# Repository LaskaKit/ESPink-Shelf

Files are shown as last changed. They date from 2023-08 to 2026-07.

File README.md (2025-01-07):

# LaskaKit ESPink-Shelf-213 and ESPink-Shelf-29 ESP32 e-Paper 

A small development board that has been designed primarily for lowest power consumption and convenient programming.</br>
This is the ESPink Shelf 213 and ESPink Shelf 29, a board equipped with [ePaper with 2.13"](https://www.laskakit.cz/good-display-gdey0213b74-2-13--250x122-epaper-displej/) and [ePaper with 2.9"](https://www.laskakit.cz/laskakit-espink-shelf-2-9-esp32-e-paper/?variantId=14193) dimension.</br>

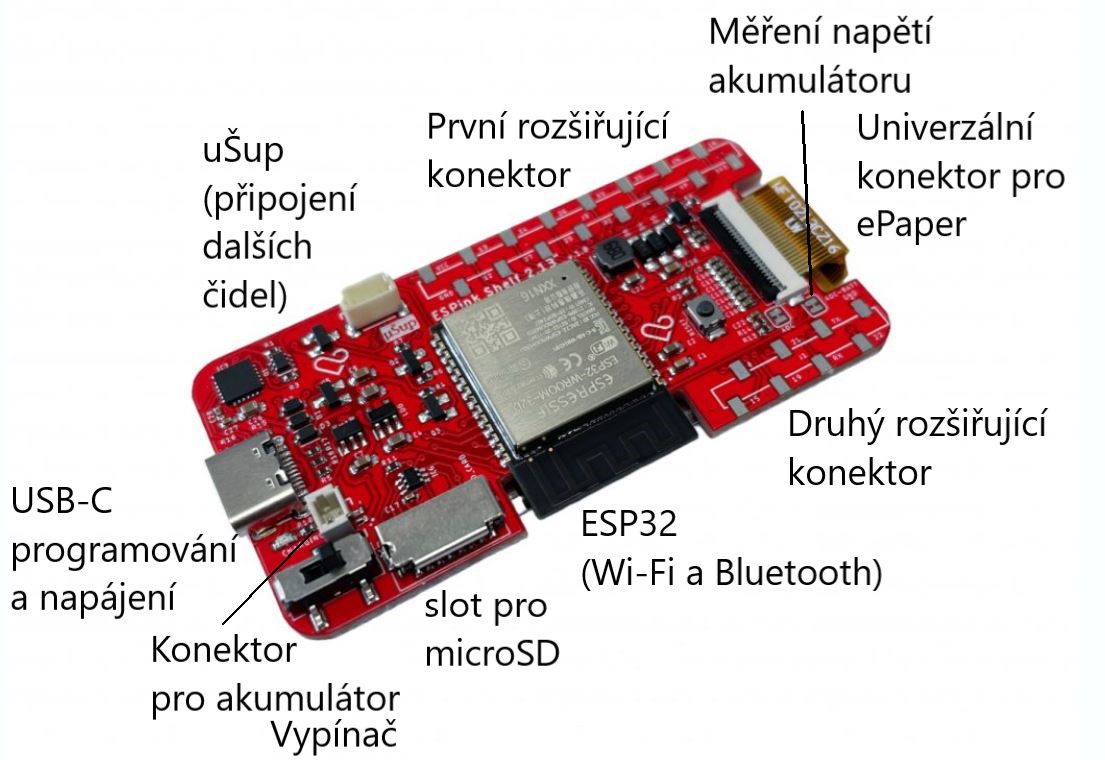
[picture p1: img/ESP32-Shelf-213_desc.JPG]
Description


And how did we achieve such a low power consumption - 12.5 uA? The ESP32 is a powerful chip that allows you to connect to Wi-Fi and Bluetooth, but it is also very power efficient, about 5 uA, even in deep-sleep mode.
The ePaper consumes power especially during the update of the display, but every uA counts so we added a MOSFET to the power supply to disconnect from source the ePaper when it is not updated.

But we don't stop there - there is also i [uŠup connector](https://blog.laskakit.cz/predstavujeme-univerzalni-konektor-pro-propojeni-modulu-a-cidel-%CE%BCsup/), this is a 4 pin connector to which we have a wide range of accessories and has a standard size and pinout. 3.3V power supply, GND and I2C bus. Accessories include [cables with variable length](https://www.laskakit.cz/--sup--stemma-qt--qwiic-jst-sh-4-pin-kabel-10cm/), [the cables with female duponts](https://www.laskakit.cz/--sup--stemma-qt--qwiic-jst-sh-4-pin-kabel-dupont-samice/) or [the cables with hooks](https://www.laskakit.cz/--sup--stemma-qt--qwiic-jst-sh-4-pin-kabel-s-testovacim-hackem/) for fast debug.  </br>

The I2C connector power supply can also be disconnected just like the ePaper - the MOSFET switches are GPIO2 control.
So the GPIO2 controlls the switching of power supply for ePaper and also for I2C sensors connected to uŠup connector. 

And what another modules you can use? For example the sensor [SCD41 for measurement of CO2, temperature and humidity](https://www.laskakit.cz/laskakit-scd41-senzor-co2--teploty-a-vlhkosti-vzduchu/), sensor SHT41 [temperature nad humidity](https://www.laskakit.cz/laskakit-sht40-senzor-teploty-a-vlhkosti-vzduchu/) and [sensor of pressure, temperature, humidity BME280](https://www.laskakit.cz/arduino-senzor-tlaku--teploty-a-vlhkosti-bme280/), [RTC - Real Time Clock](https://www.laskakit.cz/laskakit-ds3231-orig--rtc-hodiny-realneho-casu/) with DS3231 or [OLED display with 1.3" dimension and 128x64px resolution](https://www.laskakit.cz/laskakit-oled-displej-128x64-1-3--i2c/?variantId=11903).

The board can be disconnected from source thanks to switch. The USB-C connector located on the board is used for both programming and charging the battery, which you can of course plug in. 
For convenient programming, the fitted USB-UART converter CH9102F is used, which excels both in speed and low self-consumption.
If you need more memory, there is also a microSD card slot where you can store icons or images. 

There is also a voltage divider on the board that is connected to the battery and the ESP32 can measure the voltage. It can then perform an action based on the voltage - for example, to warn of a low battery voltage. The divider is connected to the GPIO34 pin.

We have prepared some sample codes for you to use with this board. The most interesting is the code called "[Date_BusConnection_WeatherForecast](https://github.com/LaskaKit/ESPink-Shelf/tree/main/SW/Date_BusConnection_WeatherForecast)", where, in addition to displaying the current date, the weather forecast and the next public transport departures - such as buses or trams - are also displayed. 

You can find the development board on our e-shop https://www.laskakit.cz/laskakit-espink-shelf-213-esp32-e-paper/
and https://www.laskakit.cz/laskakit-espink-shelf-2-9-esp32-e-paper/?variantId=14193

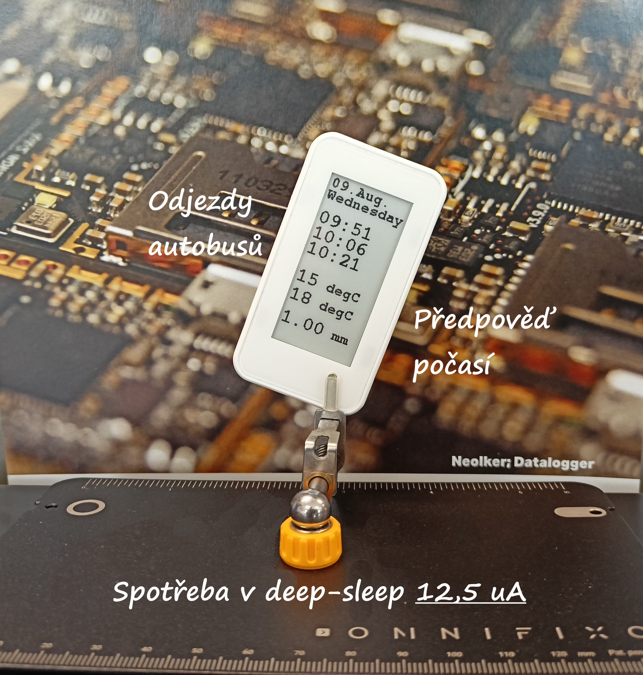
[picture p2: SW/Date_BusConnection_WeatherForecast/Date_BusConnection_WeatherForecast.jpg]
Bus


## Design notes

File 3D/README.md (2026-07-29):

#### Enclosure file moved to : https://github.com/LaskaKit/Live/tree/main/Shelf_2-13_inch and https://github.com/LaskaKit/Live/tree/main/Shelf_2-9_inch

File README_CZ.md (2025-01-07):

# LaskaKit ESPink-Shelf-213 ESP32 e-Paper a ESPink-Shelf-29

Malá, designově povedá vývojová deska, která byla navržena především na co nejnižší spotřebu proudu a pohodlné programování.</br>
To je ESPink Shelf 213 a ESPink Shelf 29, deska osazené [ePaper o velikosti 2.13"](https://www.laskakit.cz/good-display-gdey0213b74-2-13--250x122-epaper-displej/) a [ePaper o velikosti 2.9"](https://www.laskakit.cz/laskakit-espink-shelf-2-9-esp32-e-paper/?variantId=14193).</br>
[LaskaKit ESPink-4.2 ESP32 e-Paper](https://www.laskakit.cz/laskakit-espink-42-esp32-e-paper-pcb-antenna/?variantId=13538) a [LaskaKit ESPink-Shelf-4.26 ESP32 e-Paper](https://www.laskakit.cz/laskakit-espink-4-26-esp32-s3-e-paper/).</br>
Pokud preferuješ samostatnou desku, pak máme v nabídce [velmi úsporný a univerzální ESPink](https://www.laskakit.cz/laskakit-espink-esp32-e-paper-pcb-antenna/?variantId=12419). Deska je menší a univerzálnější pro připojení jiných ePaper displejů. </br>

Popis desky

A jak jsme dosáhli tak nízké, , 12,5 uA, spotřeby? ESP32 je výkonný čip umožňující se připojit na Wi-Fi a Bluetooth, ale kromě toho je velmi úsporný, cca 5 uA, i v režimu hlubokého spánku (tzv. deep-sleep mode).</br>
ePaper spotřebovává energii zejména při přepisu data na displeji, každá uA se ale počítá a tak jsme přidali na napájení MOSFET, kterým odpínáme napětí v případě, že ePaper není aktualizován. </br>
Tím ale ještě nekončíme - na desce je i[ uŠup konektor](https://blog.laskakit.cz/predstavujeme-univerzalni-konektor-pro-propojeni-modulu-a-cidel-%CE%BCsup/), to je 4 pinový konektor ke kterému máme bohaté příslušenství a má standardní rozměr a pinout. 3,3V napájení, GND a a I2C sběrnici. Mezi příslušenství patří [kabely různých délek zakončené steným konektorem](https://www.laskakit.cz/--sup--stemma-qt--qwiic-jst-sh-4-pin-kabel-10cm/), [kabely zakončený dupont dutinkami](https://www.laskakit.cz/--sup--stemma-qt--qwiic-jst-sh-4-pin-kabel-dupont-samice/) nebo [kabely zakončené háčky](https://www.laskakit.cz/--sup--stemma-qt--qwiic-jst-sh-4-pin-kabel-s-testovacim-hackem/) pro rychlé a spolehlivé testování.  </br>

Napájení I2C konektoru lze také odpojit napájení stejně jako ePaperu - MOSFET spínače jsou řízení GPIO2. </br>
GPIO2 tedy řídí/spíná jak napětí pro ePaper, tak i pro I2C čidla připojená na uŠup konektor. </br>

A jaké moduly to mohou být? Třeba čidlo [SCD41 pro měření CO2, teploty a vlhkosti vzduchu](https://www.laskakit.cz/laskakit-scd41-senzor-co2--teploty-a-vlhkosti-vzduchu/), čidla SHT41 [teploty a vlhkosti vzduchu](https://www.laskakit.cz/laskakit-sht40-senzor-teploty-a-vlhkosti-vzduchu/) a [čidla tlaku, teploty a vlhkosti vzduchu BME280](https://www.laskakit.cz/arduino-senzor-tlaku--teploty-a-vlhkosti-bme280/), [RTC Hodiny reálného času](https://www.laskakit.cz/laskakit-ds3231-orig--rtc-hodiny-realneho-casu/) s DS3231 nebo [OLED displej o velikosti 1.3" a rozlišení 128x64px](https://www.laskakit.cz/laskakit-oled-displej-128x64-1-3--i2c/?variantId=11903).

Deska lze samozřejmě kompletně vypnout díky integrovanému přepínači. USB-C konektor umístěný na desce slouží jak pro programování, tak i nabíjení akumulátoru, který můžete samozřejmě připojit. </br>
Pro pohodlné programování slouží osazený USB-UART převodník CH9102F, který vyniká jak rychlostí, tak i nízkou vlastní spotřebou.</br>
V případě potřeby větší paměti pak máme osazený ještě slot pro microSD kartu, kam můžeš uložit ikony nebo obrázky. </br>

Na desce je osazen i dělič napětí, který je připojen na akumulátor a ESP32 může měřit napětí. Na základě napětí pak provést nějakou akci - například upozornit na nízký stav napětí baterie. Dělič je připojen na pin GPIO34.</br>

Deska podporuje populární projekt Živý Obraz, který výrazně zjednodušuje použití ePaper displeje k zobrazení fotografií, (google, outlook, apple) kalendáře, kurzů, hodnot z meteostanic, předpovědi počasí a mnoho dalšího. Není nutné psát kód, stačí nahrát správný typ ePaper a desky skrze webové prostředí a dodržet postup popsaný v [dokumentaci](https://wiki.zivyobraz.eu/).</br>
Program nahraješ [přes webové prostředí na této stránce](https://zivyobraz.eu/?page=instalace) a stačí zvolit desku <b>LaskaKit ESPink 2.x</b> a typ ePaperu <b>GDEY029F51H, GDEY029T71H, GDEY029T94 nebo GDEY0213B74</b> - podle toho, co sis objednal. </br>

K této desce jsme připravili několik vzorových kódů, které můžeš využít. Nejzajímavější je kód nazvaný "[Date_BusConnection_WeatherForecast](https://github.com/LaskaKit/ESPink-Shelf/tree/main/SW/Date_BusConnection_WeatherForecast)", kde kromě zobrazení aktuálního data je zobrazena i předpověd počasí a následující odjezdy MHD - třeba autobusů nebo tramvají. 

Vývojovou desku najdeš na našem e-shopu https://www.laskakit.cz/laskakit-espink-shelf-213-esp32-e-paper/
 a https://www.laskakit.cz/laskakit-espink-shelf-2-9-esp32-e-paper/?variantId=14193

Autobusy

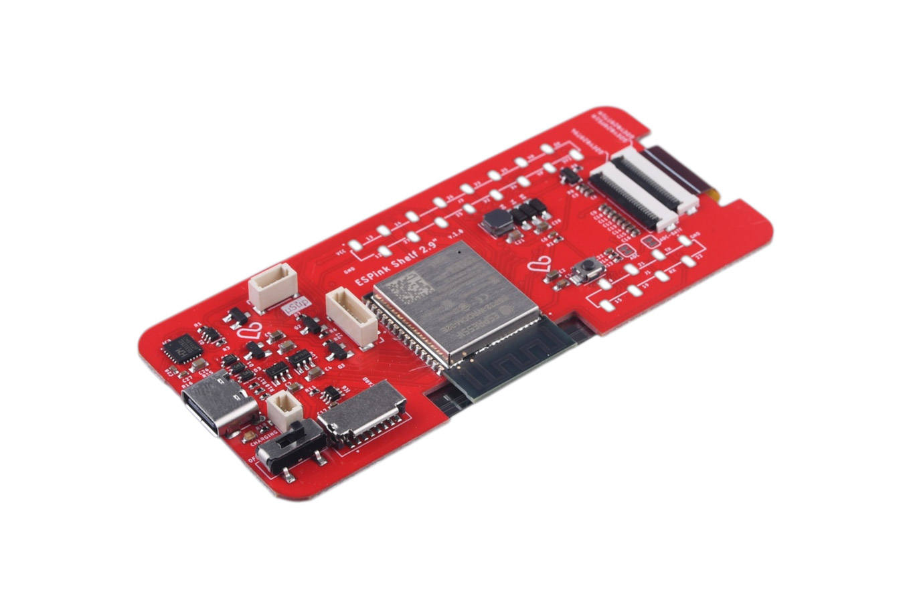
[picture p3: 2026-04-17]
img/laskakit-espink-shelf-2-9-esp32-e-paper-2.jpg

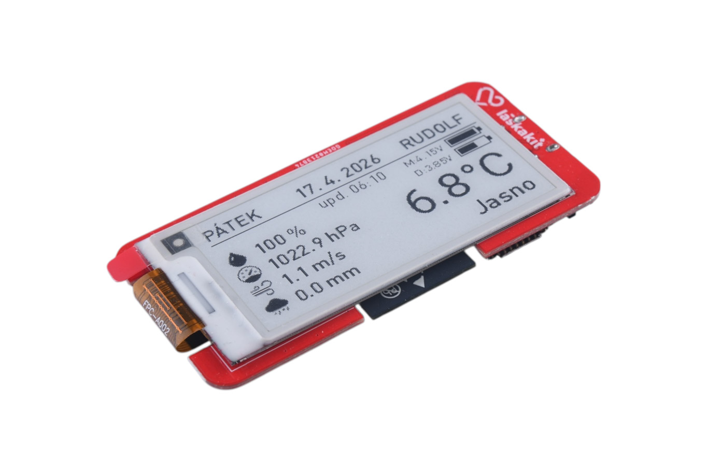
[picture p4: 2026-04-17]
img/laskakit-espink-shelf-213-esp32-e-paper-1.jpg

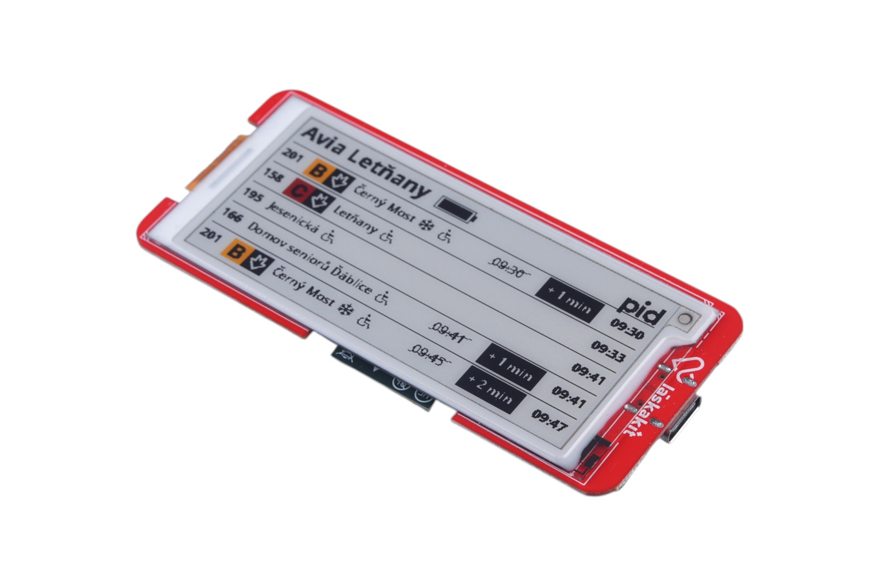
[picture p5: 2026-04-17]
img/laskakit-espink-shelf-2-9-esp32-e-paper-3.jpg

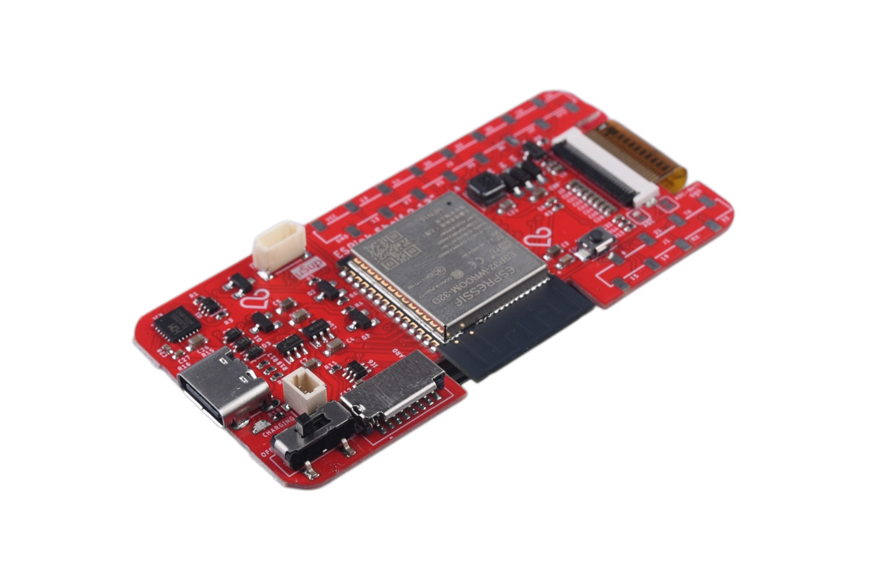
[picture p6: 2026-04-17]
img/laskakit-espink-shelf-213-esp32-e-paper-2.jpg

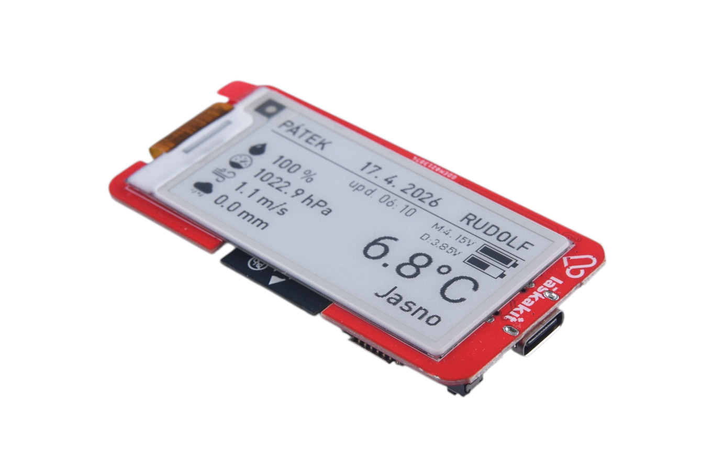
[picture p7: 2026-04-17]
img/laskakit-espink-shelf-213-esp32-e-paper-3.jpg

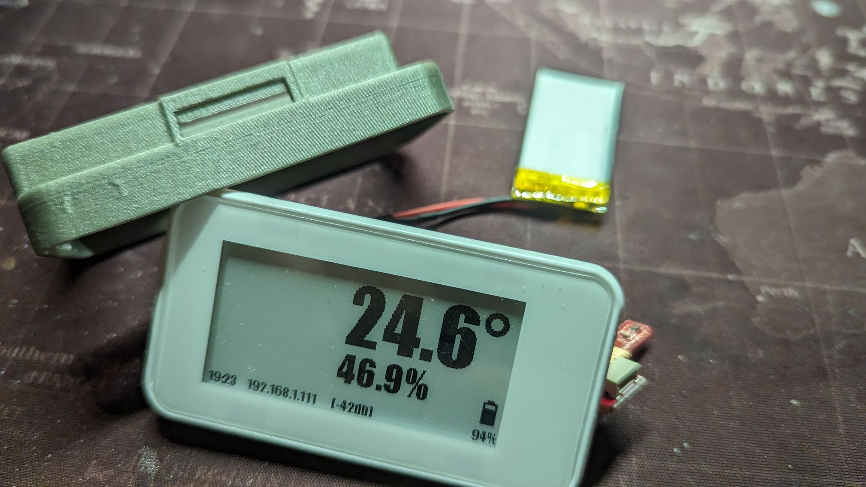
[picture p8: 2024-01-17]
SW/esphome/byHavlas/face.jpg

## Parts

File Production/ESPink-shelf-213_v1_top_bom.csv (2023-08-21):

Comment | Designator | Footprint | LCSC Part #
0.47R | R9 | R0402
1.3M | R14 | R0402
1M | R13 | R0402
1k | R5 R7 | R0402
1uF | C3 | C0402K
1uF | C7 | C0603
1uF | C8 C9 C10 C11 C12 C13 C14 C15 C16 | C0402K
4 7uF | C5 | C0603 | C108344
4.7uF | C20 | C0603
5.1k | R15 R16 | R0402
10k | R1 R2 R3 R8 R11 R17 | R0402
10uF | C21 | C0603
22uF | C4 C23 C26 | C0603
47uF | C2 | C0603 | C178330
68uH | L1 | SMNR4020 | C135265
100k | R4 R6 R18 | R0402
100n | C27 C28 | C0402
100nF | C1 | C0603
100nF | C6 | C0402K
100nF | C17 C22 | C0402
330 | R10 | R0402
AFC34-S24FIA-00 | J5 | AFC34S24FIA00
AO3400A | Q4 | SOT23-3 | C20917
AO3401 | Q3 Q5 | SOT23
BAT60B | D1 D2 D3 | SOD323-R | C514095
CH9102F | IC3 | QFN24-4X4
EN button | RESET | TS1088R02026 | C455280
ESP32-WROOM | ESP32 | ESP32WROOM32D | C529578
HT7833 | LDO | SOT23-5
JST-SH-2P | J6 | 1X02_1MM_RA_VERT | C479987
JST-SH-4P | J2 | 1X04_1MM_RA_VERT | C371588
JUMPER-SMT_2_NC_TRACE_SILK | ADC ADC-BATT | SMT-JUMPER_2_NC_TRACE_SILK
MBR0530 | D4 D5 D6 | SOD123-F
MMDT3904 | Q1 | SC70-6 | C268586
MOSFET_P-SOT-23 | Q9 | SOT23
RED | CHARGING | CHIP-LED0603 | C2286
S8050 | Q2 | SOT23-BEC
SLIDE_SWITCH_TA-3530A-A2 | S1 | TA-3530A-A2 | C514025
SMF05C | IC6 | SOT65P210X110-6N | C558425
TF-123-ARP9H17 | SD_CARD | HANBO_TF-027-H300 | C5310495
TP4054 | U1 | SOT-23-5 | C32574
USB-C_2-16PIN | J4 | USBC_USB-C-16P-5 | C2837092
X6511WVS-08H-C60D48R2 | J1 | X6511WVS08HC60D48R2
X6511WVS-16H-C60D48R1 | J3 | X6511WVS16HC60D48R2

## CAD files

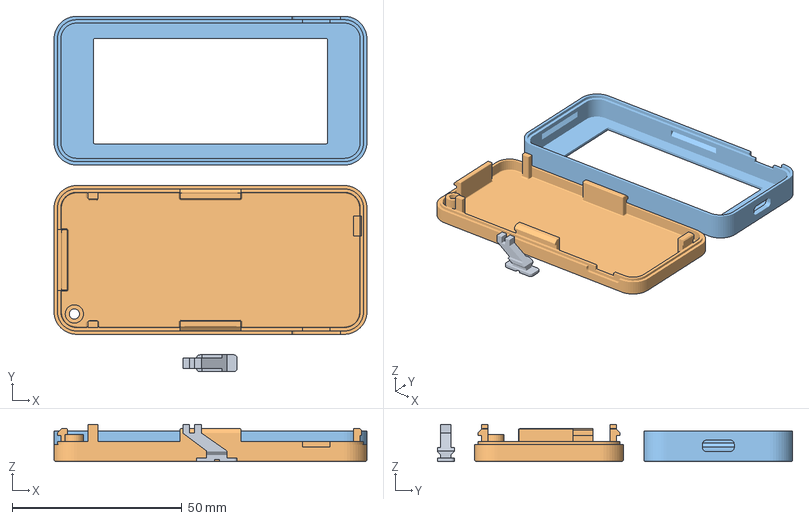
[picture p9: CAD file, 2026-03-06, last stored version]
3D/Case/ESPink-Shelf-29_case.3mf
92.1 x 104.6 x 10.9 mm
ESPink-Shelf-29_case
back v24
face v21

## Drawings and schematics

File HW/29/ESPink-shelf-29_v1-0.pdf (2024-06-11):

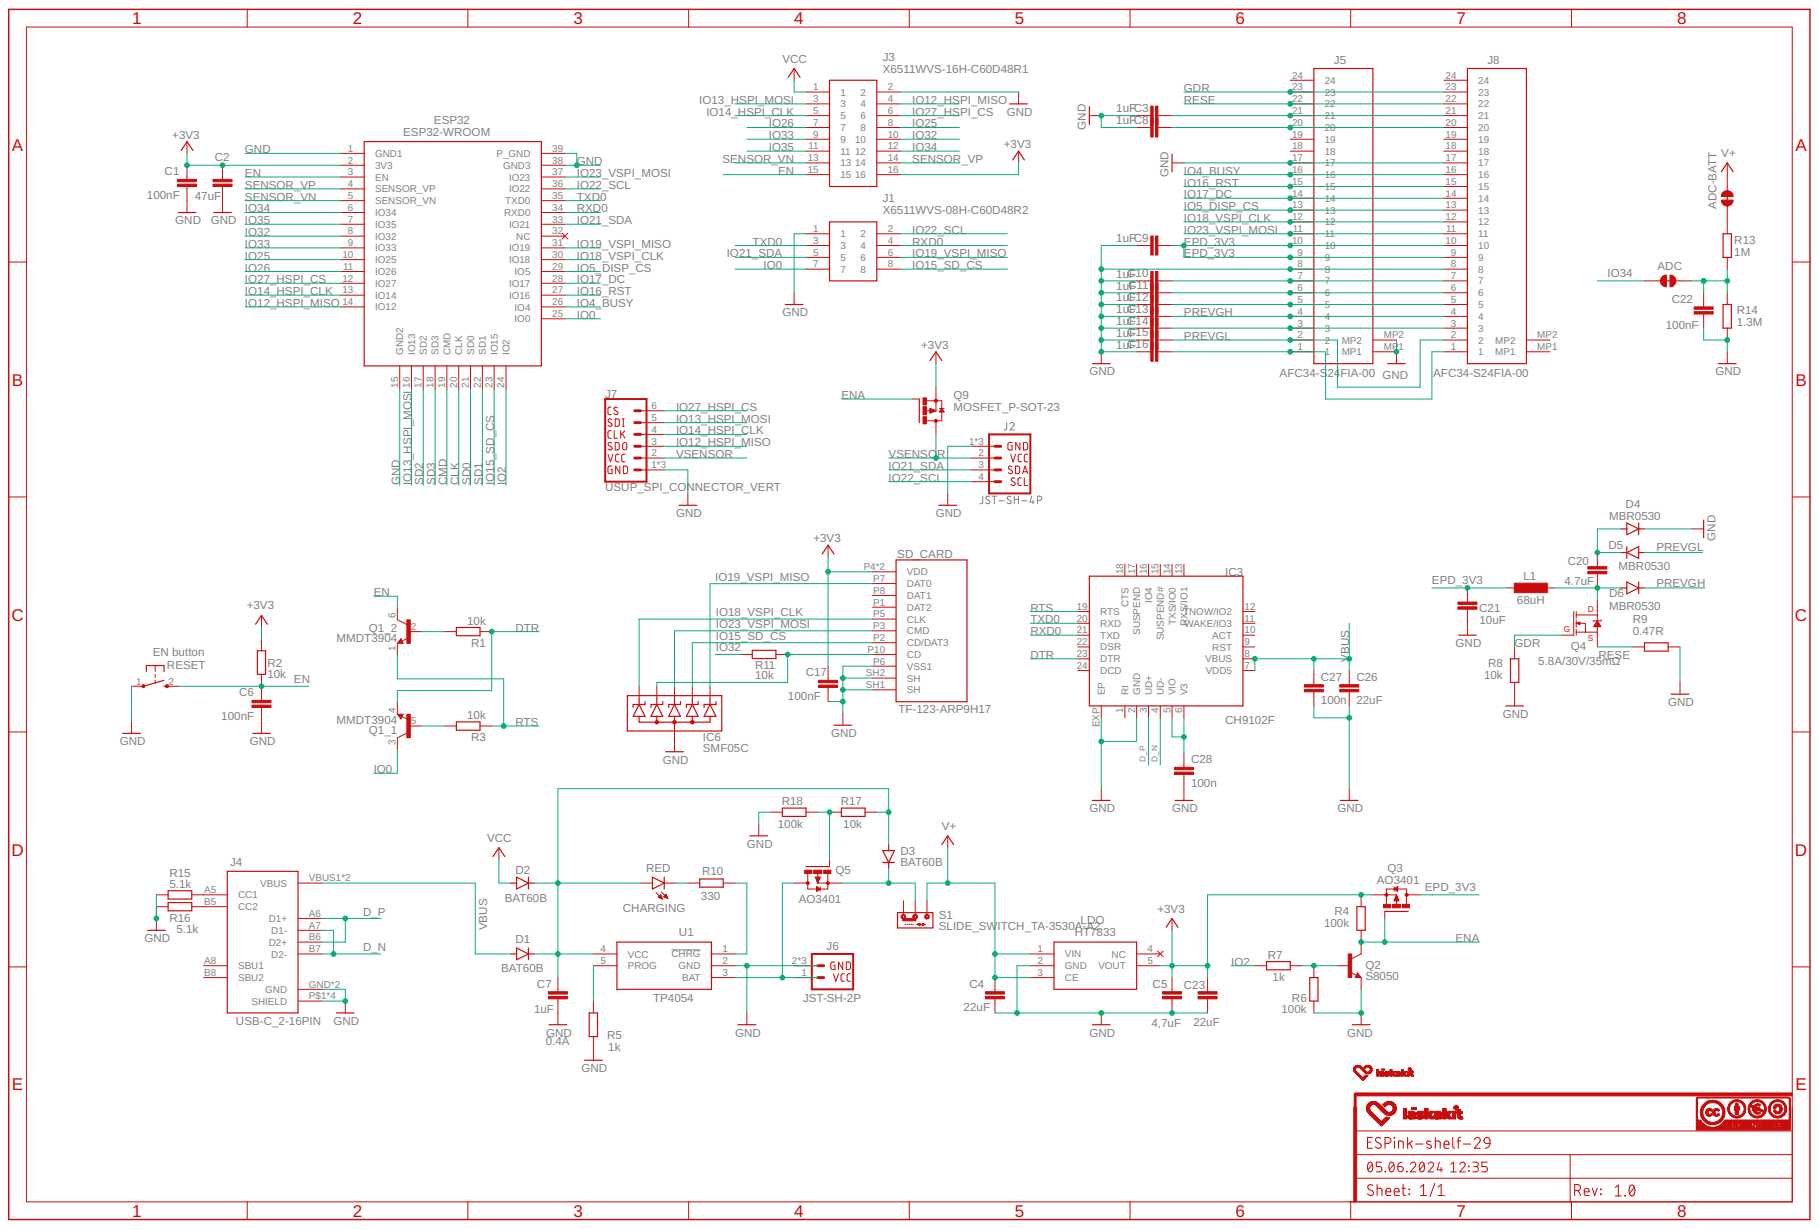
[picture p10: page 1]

1uF | 3 | 3 | 3
1uF | PREVGL 2 | | 2

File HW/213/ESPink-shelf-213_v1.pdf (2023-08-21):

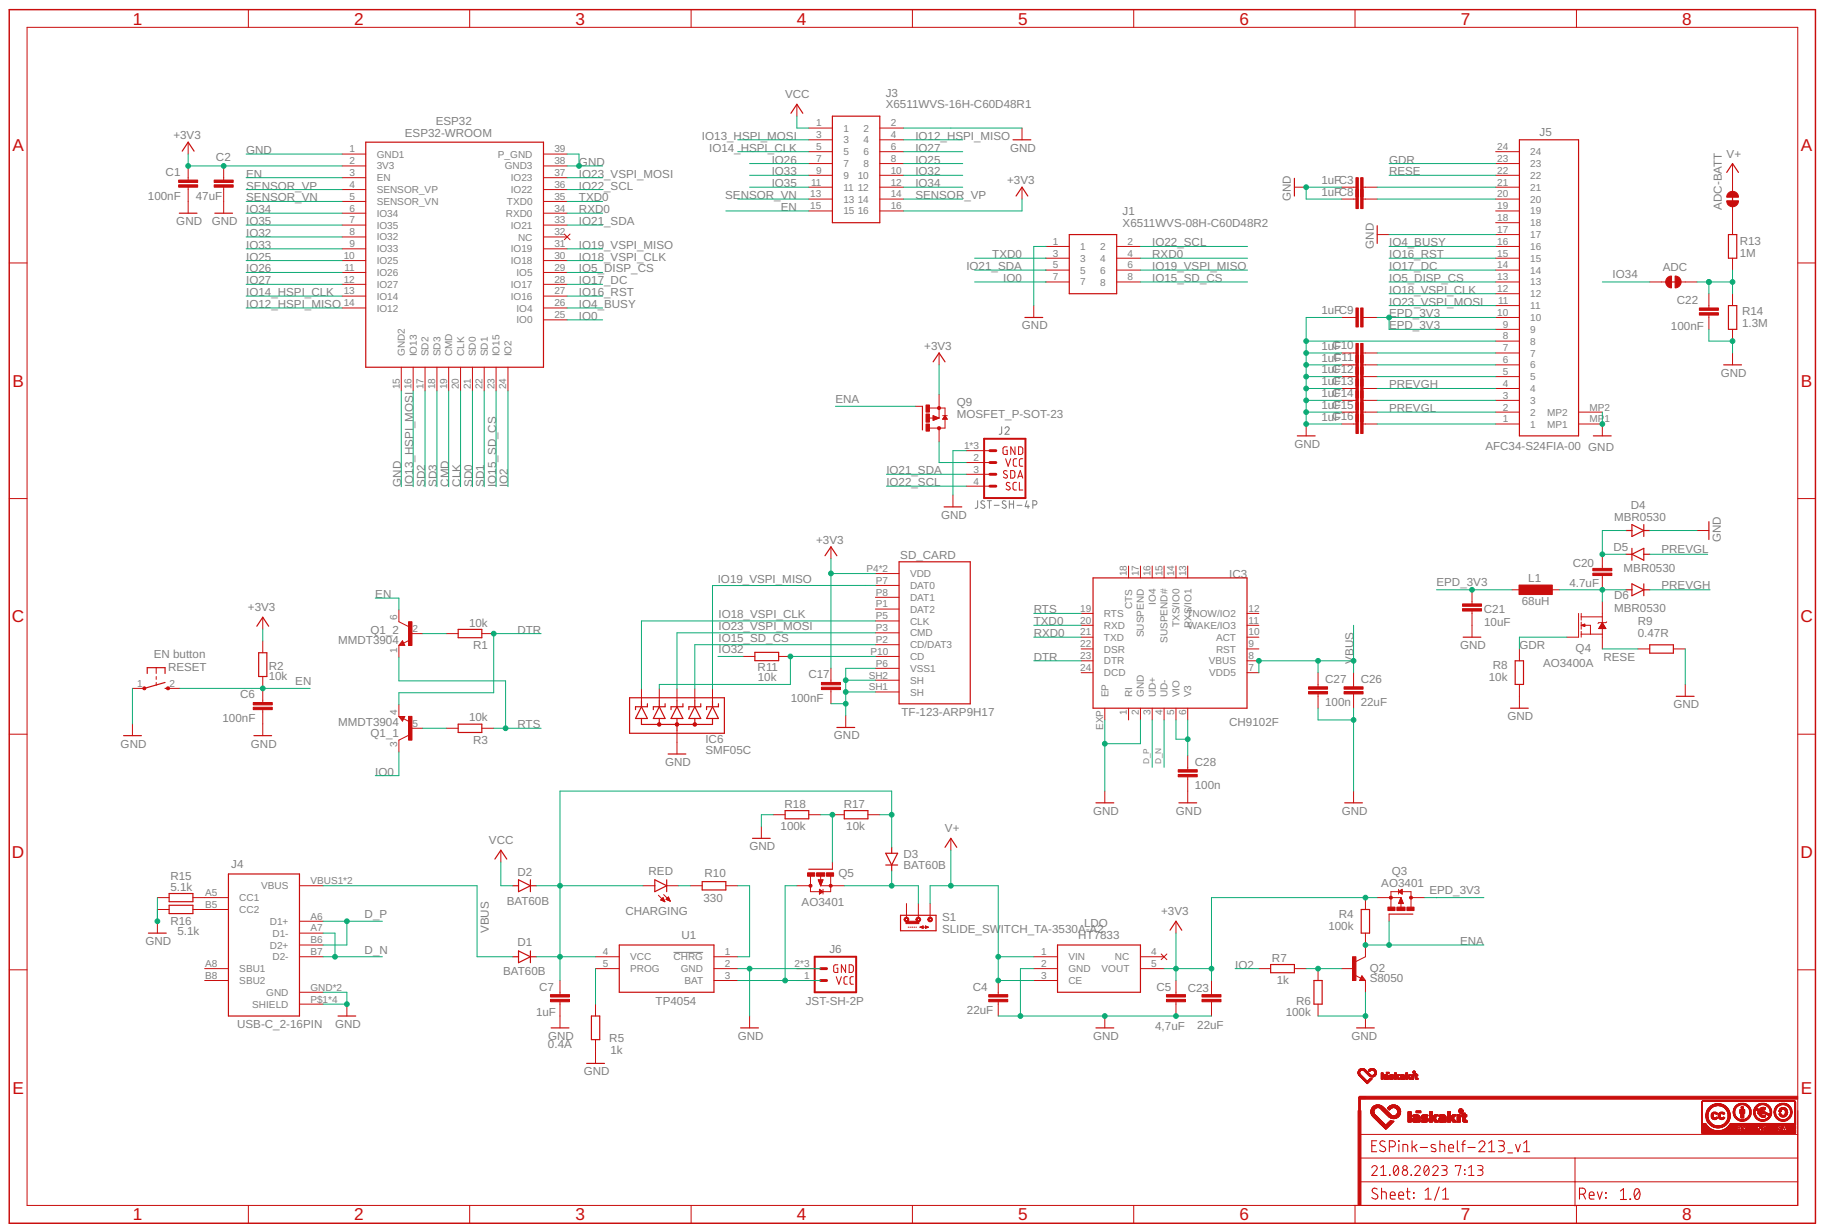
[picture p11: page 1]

1uF | 6
1uF | 5
1uF | PREVGH 4
1uF | 3
1uF | PREVGL 2
1uF | 1

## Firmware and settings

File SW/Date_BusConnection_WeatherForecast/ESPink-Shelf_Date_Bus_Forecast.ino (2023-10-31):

/* Example code for LaskaKit ESPInk-Shelf
 * where are shown the date, bus departure and weather forecast
 * 
 * Board:   LaskaKit ESPink-Shelf https://www.laskakit.cz/laskakit-espink-shelf-213-esp32-e-paper/
 * Display: Good Display GDEW0213T5D         
 * 
 * Email:podpora@laskakit.cz
 * Web:laskakit.cz
 *
 *  Libraries:
 *  ArduinoJSON https://arduinojson.org/
 *  NTP https://github.com/arduino-libraries/NTPClient
 *  GxEPD2 https://github.com/ZinggJM/GxEPD2
 *
 *  Used Forecast data from https://github.com/petrbrouzda/YrNoProvider
 *
 *	What customer shall change:
 *  Bus.h -> fill your departure time, working days, saturday and sunday are split
 *  config.h -> fill your location, Wi-Fi credentials
 */



#define ENABLE_GxEPD2_GFX 0

#include <WiFi.h>
#include <HTTPClient.h>

/*------- CONFIGURATION ----------*/
#include "config.h"

/*------- Arduino JSON ----------*/
#include <ArduinoJson.h>

/*------- BUS connection ----------*/
#include "Bus.h"

/*------- NTP ----------*/
#include "time.h"

/*------- ePaper ----------*/
#include <GxEPD2_BW.h>
#include <GxEPD2_3C.h>
#include <GxEPD2_7C.h>
#include <Fonts/FreeMonoBold9pt7b.h>
#include <Fonts/FreeMonoBold12pt7b.h>
#include <Fonts/FreeMonoBold18pt7b.h>
#include <Fonts/FreeMonoBold24pt7b.h>

//GxEPD2_BW<GxEPD2_213_T5D, GxEPD2_213_T5D::HEIGHT> display(GxEPD2_213_T5D(/*CS=5*/ SS, /*DC=*/ 17, /*RST=*/ 16, /*BUSY=*/ 4));         // ESPink-Shelf-213 GDEW0213T5D -> 2.13" 104x212, UC8151D
GxEPD2_BW<GxEPD2_213_B74, GxEPD2_213_B74::HEIGHT> display(GxEPD2_213_B74(/*CS=5*/ SS, /*DC=*/ 17, /*RST=*/ 16, /*BUSY=*/ 4));     // ESPink-Shelf-213 GDEM0213B74 -> 2.13" 122x250, SSD1680 

/*------- NTP ----------*/
struct tm timeinfo;

/*------- Arduino JSON config ----------*/
StaticJsonDocument<10000> doc;

void setup()
{
  Serial.begin(115200);
  delay(100);

  WiFi.begin(ssid, pass);
  Serial.println("Connecting");
  int count = 0;
  while(WiFi.status() != WL_CONNECTED) {
    delay(500);
    Serial.print(".");
    count++;
    if(count >= 20) // wait max 20s, if it is not connected, go to sleep
    {
      Serial.flush();
      esp_sleep_enable_timer_wakeup(sleepDuration * 1000000); // sleep for 10 minutes
      esp_deep_sleep_start(); 
    }
  }
  Serial.println();

  // WiFi connected
  if(WiFi.status()== WL_CONNECTED)
  {
    // turn on power to display
    pinMode(2, OUTPUT);
    digitalWrite(2, HIGH);   // turn on the ePaper
    delay(1000);   
    
    display.init(); // ePaper init
    display.setRotation(0);
    display.setTextColor(GxEPD_BLACK); // Set text color
    display.fillScreen(GxEPD_WHITE); // set the background to white (fill the buffer with value for white)

	/*------- Forecast ----------*/
    updateForecastData(jsonurl);
	
    /*------- NTP ----------*/
    configTime(gmtOffset_sec, daylightOffset_sec, ntpServer);
    
    if(!getLocalTime(&timeinfo))
    {
      Serial.flush();
      esp_sleep_enable_timer_wakeup(sleepDuration * 1000000); 
      esp_deep_sleep_start();
      Serial.println("Failed to obtain time");
      return;
    }
    Serial.println(&timeinfo, "%A, %B %d %Y %H:%M:%S");
    Serial.println(timeinfo.tm_wday);

    display.setFont(&FreeMonoBold9pt7b);
    display.setCursor(5, 15);
    display.print(&timeinfo, "%d.%b.");
    display.setCursor(5, 30);
    display.print(&timeinfo, "%A");
	
	  /*------- BUS connection ----------*/
	  updateBUSconnectionData();

    /*------- Update ePaper ----------*/
    display.display(false);

    display.powerOff();

    digitalWrite(2, LOW);   // turn off the ePaper
  }
  
  Serial.flush();
  esp_sleep_enable_timer_wakeup(sleepDuration * 1000000); 
  esp_deep_sleep_start(); 

}


void loop()
{
}

void updateBUSconnectionData()
{
	    /*------- Bus connection ----------*/
    int firstDepartureHour = 4; // first hour of departure
    int lastDepartureHour = 22; // last hour of departure
    int maxDepartureCount = 3; // max visible departures

    /*   DO NOT CHANGE IT  */
    int currMin = timeinfo.tm_min; // current minute from NTP server
    int currHour = timeinfo.tm_hour; // current hour from NTP server
    int departureCount = 0; // temp variable
    int posY = 60; // px possition of the first bus on ePaper (Y axis)
    int posX = 5; // px possition of the first bus on ePaper (X axis)
    int posYmove = 20; // move the next departure by this px number on ePaper
    display.setCursor(posX, posY);
    display.setFont(&FreeMonoBold12pt7b);

    // if current hour is in the range of firstDepartureHour and lastDepartureHour
    if((currHour >= firstDepartureHour) && (currHour <= lastDepartureHour))
    {
      Serial.println("Following BUS connection");
      for(int i = 1; i <= 9; i++) // search BUS between 1 to 9 time slot , means firstConnectionInMinutes, secondConnectionInMinutes, ...
      {
          int minuteConnection = 0;
          
          minuteConnection = busDepartureWD[currHour-firstDepartureHour][i]; // Working day array
          if((timeinfo.tm_wday == 0) || (timeinfo.tm_wday == 6)) // if Sunday, choose different array
          {
            if(timeinfo.tm_wday == 0)
            {
              minuteConnection = busDepartureSun[currHour-firstDepartureHour][i];
              Serial.println("Sunday");
            }
            if(timeinfo.tm_wday == 6)
            {
              minuteConnection = busDepartureSat[currHour-firstDepartureHour][i];
              Serial.println("Saturday");
            }
          }
            
          if((minuteConnection) == -1) // if no connection, exit the loop 
          {
              Serial.print("No BUS connection in "); Serial.println(currHour);
              break;
          }
          else // else show folling connection
          {
              if(currMin <= (minuteConnection))
              {
                  display.setTextColor(GxEPD_BLACK);

                  char departure[10] = {0};
                  sprintf(departure, "%02d:%02d", currHour, minuteConnection);
                  display.setCursor(posX, posY);
                  display.println(departure);
                  Serial.print("Next BUS connection in "); Serial.print(currHour); Serial.print(":"); Serial.println(minuteConnection);
                  departureCount++;
                  posY = posY + posYmove;
                  if(departureCount >= maxDepartureCount) // show mayDepartureCount connection
                  {
                      break;
                  }
              }
          }
      }
    }
    // if no connection, show first morning connection
    else
    {
        display.setCursor(posX, posY);
        int minuteConnection = 0;
        minuteConnection = busDepartureWD[firstDepartureHour-firstDepartureHour][1];
        if((timeinfo.tm_wday == 0) || (timeinfo.tm_wday == 6)) // if Sunday, choose the array for Sunday
        {
          if(timeinfo.tm_wday == 0)
          {
            minuteConnection = busDepartureSun[firstDepartureHour-firstDepartureHour][1];
            Serial.println("Sunday");
          }
          if(timeinfo.tm_wday == 6)
          {
            minuteConnection = busDepartureSat[currHour-firstDepartureHour][1];
            Serial.println("Saturday");
          }
        }

        char departure[10] = {0};
        sprintf(departure, "%02d:%02d", firstDepartureHour, minuteConnection);
        display.println(departure);
        Serial.print("Next BUS connection in "); Serial.print(firstDepartureHour); Serial.print(":"); Serial.println(minuteConnection);
    }

    // if less connection than maxDepartureCount, search the connection in the next hour
    if((departureCount < maxDepartureCount) && ((currHour >= firstDepartureHour) && (currHour <= lastDepartureHour)))
    {
        currHour = currHour + 1; // current hour + 1
        currMin = 0;
        
        if((currHour >= firstDepartureHour) && (currHour <= lastDepartureHour)) // check the hour is in the range
        {
          for(int i = 1; i <= 9; i++) // search minutes of connetions (first, second, ...)
            {
              int minuteConnection = 0;
              minuteConnection = busDepartureWD[currHour-firstDepartureHour][i];
              if((timeinfo.tm_wday == 0) || (timeinfo.tm_wday == 6)) // if Sunday, choose the Sunday array
              {
                if(timeinfo.tm_wday == 0)
                {
                  minuteConnection = busDepartureSun[currHour-firstDepartureHour][i];
                  Serial.println("Sunday");
                }
                if(timeinfo.tm_wday == 6)
                {
                  minuteConnection = busDepartureSat[currHour-firstDepartureHour][i];
                  Serial.println("Saturday");
                }
              }
                
              if((minuteConnection) == -1) // if no connection in the hour+1, break it
              {
                  Serial.print("In "); Serial.print(currHour); Serial.println(" is not BUS connection");
                  break;
              }
              else // show the connection in hour+1
              {
                  if(currMin <= (minuteConnection))
                  {
                      display.setTextColor(GxEPD_BLACK);
                    
                      display.setCursor(posX, posY);
                      char departure[10] = {0};
                      sprintf(departure, "%02d:%02d", currHour, minuteConnection);
                      display.println(departure); 
                      Serial.print("Next BUS connection in "); Serial.print(currHour); Serial.print(":"); Serial.println(minuteConnection);
                      departureCount++;
                      posY = posY + posYmove;
                      currMin = (minuteConnection);
                      if(departureCount >= maxDepartureCount)
                      {
                          break;
                      }
                  }
              }
            }
        }
        else // if no connection, choose the first morning connection
        {
          display.setCursor(posX, posY);
          int minuteConnection = 0;
          minuteConnection = busDepartureWD[firstDepartureHour-firstDepartureHour][1];
          if((timeinfo.tm_wday == 0) || (timeinfo.tm_wday == 6)) // if Sunday, choose the Sunday array
          {
            if(timeinfo.tm_wday == 0)
            {
              minuteConnection = busDepartureSun[firstDepartureHour-firstDepartureHour][1];
              Serial.println("Sunday");
            }
            if(timeinfo.tm_wday == 6)
            {
              minuteConnection = busDepartureSat[currHour-firstDepartureHour][1];
              Serial.println("Saturday");
            }
          }

          char departure[10] = {0};
          sprintf(departure, "%02d:%02d", firstDepartureHour, minuteConnection);
          display.println(departure);
          Serial.print("Next BUS connection in "); Serial.print(firstDepartureHour); Serial.print(":"); Serial.println(minuteConnection);
        }
    }
    departureCount = 0; // clear temp variable 
}

void updateForecastData(const char *URL) {
  HTTPClient http;
  http.begin(URL);

  int httpCode = http.GET();
  if (httpCode == HTTP_CODE_OK) {
    int err = jsonDecoder(http.getString(), true);
    switch (err) {
      case 0:
        Serial.println("JSON parsing done!");
        break;
      case -1:
        Serial.println("Wrong JSON format");
        break;
      case -2:
        Serial.println("Low memory, increase the StaticJsonDocument");
        break;
      case -3:
        Serial.println("Error during parsing of JSON");
        break;
    }
  }
  http.end();
}

int jsonDecoder(String s, bool log) {
  DeserializationError e = deserializeJson(doc, s);
  if (e) {
    if (e == DeserializationError::InvalidInput) {
      return -1;
    } else if (e == DeserializationError::NoMemory) {
      return -2;
    } else {
      return -3;
    }
  } else {

    int temp_min = doc["sections"][0]["temp_min"]; // decimal number is ignored
    int temp_max = doc["sections"][0]["temp_max"]; // decimal number is ignored
    float rain_sum = doc["sections"][0]["rain_sum"];

    Serial.print("Temp min: "); Serial.println(temp_min);
    Serial.print("Temp max: "); Serial.println(temp_max);
    Serial.print("Rain_sum: "); Serial.println(rain_sum); 

    /*------- Show weather forecast ----------*/
    display.setCursor(5, 130);
    display.setFont(&FreeMonoBold12pt7b);
    display.print(temp_min);
    display.setFont(&FreeMonoBold9pt7b);
    display.print(" degC");

    display.setCursor(5, 160);
    display.setFont(&FreeMonoBold12pt7b);
    display.print(temp_max);
    display.setFont(&FreeMonoBold9pt7b);
    display.print(" degC");

    display.setCursor(5, 190);
    display.setFont(&FreeMonoBold12pt7b);
    display.print(rain_sum);
    display.setFont(&FreeMonoBold9pt7b);
    display.print(" mm");

    }
    return 0;
}

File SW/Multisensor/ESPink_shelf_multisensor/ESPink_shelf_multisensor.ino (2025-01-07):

/*
* This example code for Temperature and Humidity - SHTxx module
* or Temperature and Humidity and CO2 - SCD41 module
* or Temperature and Humidity and Pressure - BME280
* with ESPink Shelf 2.13".
* ESPink Shelf reads variables and shows on ePaper 2.13" based on conencted sensor
*
* SDA - GPIO21
* SCL - GPIO22
* ENABLE voltage for ePaper and I2C sensor - GPIO2 (HIGH - turn on, LOW - turn off)
*
* Made by (c) laskakit.cz 2024
*
* Libraries
* https://github.com/adafruit/Adafruit_SHT4X
* https://github.com/sparkfun/SparkFun_SCD4x_Arduino_Library
* https://github.com/adafruit/Adafruit_BME280_Library
* https://github.com/ZinggJM/GxEPD2
*
* Compilation: if you will select 40 MHz osc instead of 240 MHz (Wi-Fi is not used)
* you reduce the own consumption by (approx) 50%
*/
 
#include <WiFi.h>
#include <Wire.h>

  // SHT40/41/45
  #include "Adafruit_SHT4x.h"
Adafruit_SHT4x sht4 = Adafruit_SHT4x();
  //SCD40/41
  #include "SparkFun_SCD4x_Arduino_Library.h"
SCD4x SCD4(SCD4x_SENSOR_SCD41);
  //BME280
  #include <Adafruit_Sensor.h>
  #include <Adafruit_BME280.h>
Adafruit_BME280 bme;

/*------- ePaper ----------*/
#include <GxEPD2_BW.h>
#include <Fonts/FreeMonoBold12pt7b.h>

//#include "Monospaced_bolditalic_70.h"
#include "Monospaced_bolditalic_50.h"
#include "Monospaced_bolditalic_30.h"
#include "Monospaced_bold_15.h"

// select the correct type of ePaper on 2.13" ESPink shelf
//GxEPD2_BW<GxEPD2_213_T5D, GxEPD2_213_T5D::HEIGHT> display(GxEPD2_213_T5D(/*CS=5*/ SS, /*DC=*/ 17, /*RST=*/ 16, /*BUSY=*/ 4));         // ESPink-Shelf-213 GDEW0213T5D -> 2.13" 104x212, UC8151D
GxEPD2_BW<GxEPD2_213_B74, GxEPD2_213_B74::HEIGHT> display(GxEPD2_213_B74(/*CS=5*/ SS, /*DC=*/ 17, /*RST=*/ 16, /*BUSY=*/ 4));     // ESPink-Shelf-213 GDEM0213B74 -> 2.13" 122x250, SSD1680 

/*------- Analog Read ----------*/
#define deviderRatio 1.769
#define ADC 34

float temperature = 0.0;
int humidity = 0;
int co2 = 0;
int pressure = 0;

uint8_t checkSensors(void);

/*------- Sleep time ----------*/
const int sleepDuration = 60;
 
void setup() {
  //adc_power_off();
  WiFi.disconnect(true);  // Disconnect from the network
  WiFi.mode(WIFI_OFF);    // Switch WiFi off
  
  Serial.begin(115200);

  /*------- Enable voltage for ePaper and I2C sensor ----------*/
  pinMode(2, OUTPUT);
  digitalWrite(2, HIGH);   // turn on the ePaper
  delay(100);
  // I2C init
  Wire.begin(21, 22);
 
  /*------- Battery voltage ----------*/
  float volt = 0.0;
  // battery voltage measurement
  volt = (analogReadMilliVolts(ADC) * deviderRatio / 1000);

  /*------- ePaper init ----------*/
  display.init(); // ePaper init
  display.setRotation(1);
  display.setTextColor(GxEPD_WHITE); // Set text color
  display.fillScreen(GxEPD_WHITE); // set the background to white (fill the buffer with value for white)

  display.fillRect(0, 90, 255, 90, GxEPD_BLACK);
  display.setFont(&Monospaced_bold_15);
  display.setCursor(180, 110);
  display.print(volt);
  display.print(" V");

  if(volt < 3.4)
  {
    display.setTextColor(GxEPD_BLACK);
    display.setFont(&Monospaced_bolditalic_30);
    display.setCursor(10, 60);
    display.print("VYBITA BATERIE");
  }
  else
  {
    if(volt < 3.7)
    {
      display.setTextColor(GxEPD_WHITE);
      display.setFont(&Monospaced_bold_15);
      display.setCursor(5, 110);
      display.print("VYBITA BATERIE");
    }

    display.setTextColor(GxEPD_BLACK); // Set text color

    uint8_t sensor = checkSensors();
    /*------- Update ePaper ----------*/
    /*------- SHT40 (temperature, humidity) ----------*/
    if(sensor == 1)
    {
      display.setFont(&Monospaced_bolditalic_50);
      display.setCursor(5, 60);
      display.print(String(temperature, 1));

      display.setCursor(180, 60);
      display.print(humidity); 
    }
    /*------- SCD41 (temperature, humidity, CO2) ----------*/
    else if(sensor == 2)
    {
      display.setFont(&Monospaced_bolditalic_50);
      display.setCursor(5, 60);
      display.print(co2);

      display.setFont(&Monospaced_bolditalic_30);
      display.setCursor(165, 30);
      display.print(String(temperature, 1)); 
      display.setCursor(165, 70);
      display.print(humidity); 
    }
    /*------- BME280 (temperature, humidity, pressure) ----------*/
    else if(sensor == 3)
    {
      display.setFont(&Monospaced_bolditalic_50);
      display.setCursor(5, 60);
      display.print(String(temperature, 1));

      display.setFont(&Monospaced_bolditalic_30);
      display.setCursor(165, 30);
      display.print(String(pressure)); 
      display.setCursor(165, 70);
      display.print(humidity); 
    }
    else
    {
      display.setFont(&Monospaced_bold_15);
      display.setCursor(0, 50);
      display.print("Cidlo nenalezeno");
    }
  }
    // ePaper refresh
    display.display(false);
    // SW turn off
    display.powerOff();
    // HW turn off
    digitalWrite(2, LOW); 

    // sleep
    Serial.flush();
    esp_sleep_enable_timer_wakeup(sleepDuration * 1000000); 
    esp_deep_sleep_start(); 
}
 
void loop() {

}

uint8_t checkSensors()
{
  // Check SHT40 OR SHT41 OR SHT45
  if (!sht4.begin())
  {
    Serial.println("SHT4x not found - maybe just not connected? Otherwise check its wiring.");
  }
  else
  {
    Serial.println("SHT4x FOUND");
    sht4.setPrecision(SHT4X_LOW_PRECISION); // highest resolution
    sht4.setHeater(SHT4X_NO_HEATER); // no heater


    sensors_event_t hum, temp; // temperature and humidity variables
    sht4.getEvent(&hum, &temp);

    temperature = temp.temperature;
    humidity = hum.relative_humidity;

    return 1;
  }

  // Check SCD40 OR SCD41
  if (!SCD4.begin(false, true, false))
  {
    Serial.println("SCD41 not found - maybe just not connected? Otherwise check its wiring.");
  }
  else
  {
    Serial.println("SCD4x FOUND");
    SCD4.measureSingleShot();

    while (SCD4.readMeasurement() == false) // wait for a new data (approx 30s)
    {
      Serial.println("Waiting for first measurement...");
      delay(1000);
    }

    temperature = SCD4.getTemperature()+2;
    humidity = SCD4.getHumidity();
    co2 = SCD4.getCO2();

    return 2;
  }

  // Check BME280
  if(!bme.begin())
  {
    Serial.println("BME280 not found - maybe just not connected? Otherwise check its wiring.");
  }
  else
  {
    Serial.println("BME280 FOUND");

    temperature = bme.readTemperature();
    humidity = bme.readHumidity();
    pressure = bme.readPressure() / 100.0F;

    return 3;
  }

  return 0;
}

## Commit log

2023-08-21 new data
    [ESPink-shelf-213_v1_top_bom.csv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]
2023-10-31 Update ESPink-shlef_SHT40.ino
    a new ESPInk shelf driver
2023-10-31 Update ESPink-Shelf_Date_Bus_Forecast.ino
    a new EPSink shelf driver
2024-06-28 new test version
    [ESPink-shelf-29_top_bom (2).csv, ESPink-shelf-29_top_bom.csv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]
2025-01-04 Update README_CZ.md
    added other espink boards
